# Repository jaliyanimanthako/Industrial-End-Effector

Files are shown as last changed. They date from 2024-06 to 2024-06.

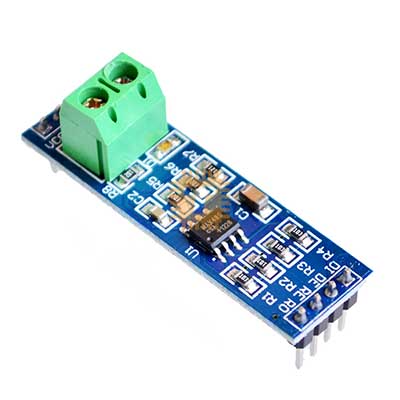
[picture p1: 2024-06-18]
Data Sets and Components/rs485.jpg

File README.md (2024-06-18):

# Industrial End Effector for Automated Pick and Place Robots

This repository contains the hardware and software documentation for an industrial end effector designed for automated pick and place robots. The project integrates ToF (Time-of-Flight) sensors with a vacuum gripper, facilitating precise orientation detection and efficient communication with robot control panels.

## Overview

The project focuses on:
- Integrating ToF sensors (VL53L0X) for accurate measurement of box yaw and pitch angles.
- Using Modbus protocol over USB for seamless data transmission.
- Designing a robust PCB layout and enclosure to optimize space and ensure reliable operation in industrial environments.

## Features

- **Modbus Protocol Integration**: Enables reliable serial communication between the end effector and robot control panels.
- **ToF Sensors (VL53L0X)**: Facilitates precise box orientation detection essential for pick and place operations. 
  - *Library Usage*: Includes a detailed comparison between library usage and direct register-level programming for optimizing memory usage.
- **MAX485 TTL to RS485 Converter Module**: Converts TTL signals for long-distance communication.  
- **USB to RS485 Communication Module**: Used for debugging and monitoring via PC.

  rs485

- **PCB Design**: Optimized layout for component integration and space efficiency.

WhatsApp Image 2024-06-18 at 14 25 22_f2b9fc5d

- **Enclosure Design**: Ensures secure attachment and robust mechanical strength for various vacuum gripper sizes.
  - *Adjustable Design Challenges*: Discusses challenges and solutions related to accommodating different vacuum gripper sizes.
  - *Final Design*: Details the chosen enclosure design tailored for specific vacuum gripper models.

## Components

- **Microcontroller**: ATMEGA2560-16AU for data handling and communication.
- **Multiplexer**: PCA9546ADG4 manages I2C signals from multiple ToF sensors.
- **Crystal Oscillator**: ABLS2-16.000MHZ-D4Y-T provides stable clock signal.
- **Capacitors, Resistors, LEDs**: Essential components for power management, circuit configuration, and status indication.
- **Headers and Connectors**: Facilitate external connections and USB connectivity.

## Usage

1. **Setup**:
   - Connect the ToF sensors and components as per the hardware documentation.
   - Ensure proper power supply and USB connectivity for data transmission.

2. **Programming**:
   - Use the provided software libraries or customize firmware based on project requirements.
   - Implement Modbus communication protocols for seamless integration with robot control systems.

3. **Testing and Debugging**:
   - Utilize Modbus Poll software for monitoring data transmission and debugging.
   - Verify sensor accuracy and functionality before deployment.

## Enclosure Design

The enclosure design ensures:
- Secure attachment and mechanical strength suitable for various vacuum gripper models.
- Dedicated mounting places for ToF sensors (VL53L0X) to avoid interference with gripper functionality.
- Features like air vents for heat dissipation and mounting bosses for PCB, ensuring robustness and ease of access.

</p center>
 
 </p>



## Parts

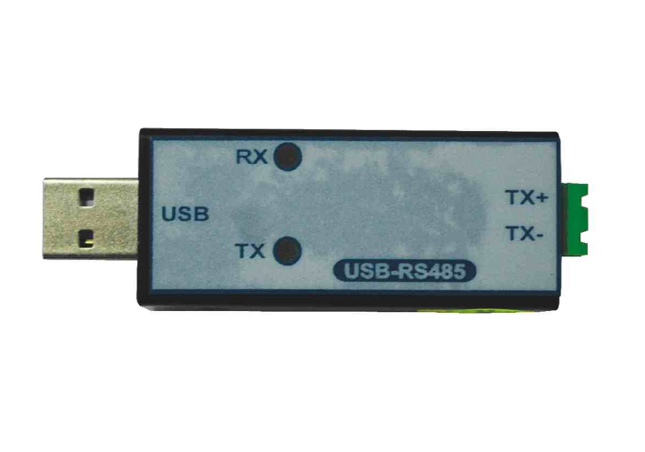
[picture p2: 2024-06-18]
Data Sets and Components/usb.png

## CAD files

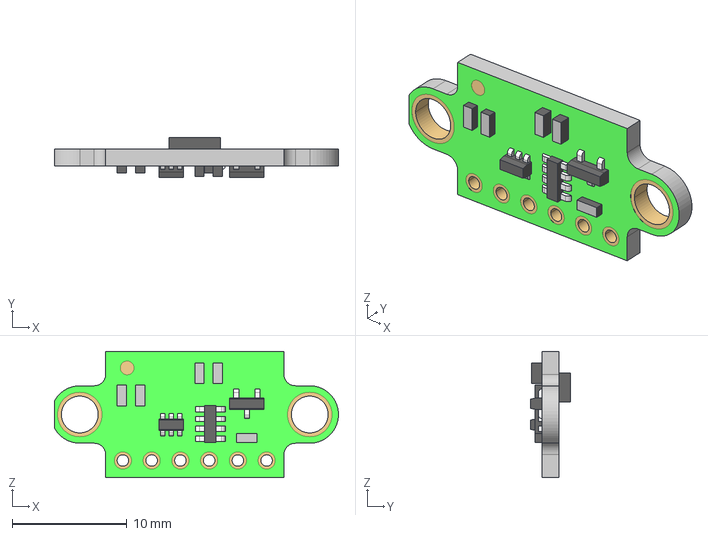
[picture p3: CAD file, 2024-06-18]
Data Sets and Components/vl53l0x for conceptual.stp
24.7 x 3.50 x 11.0 mm

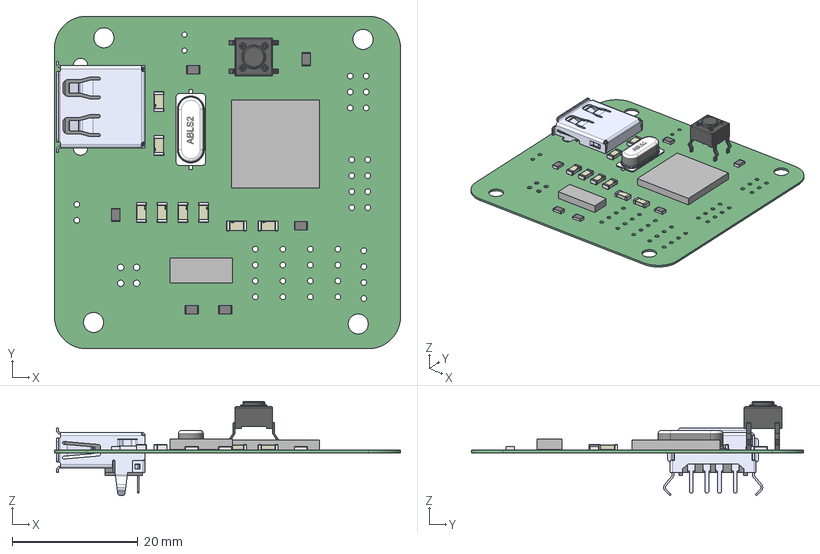
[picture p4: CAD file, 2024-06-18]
Enclosure Designs/PCB2 For Conceptual.step
55.1 x 53.0 x 15.0 mm
Mid_Body x 6
Mark x 6
Cap_KEMET_C1206C472K4RACTU_eec x 24
Extruded x 2
Switch_C&K_PTS645SM43SMTR92LFS_eec

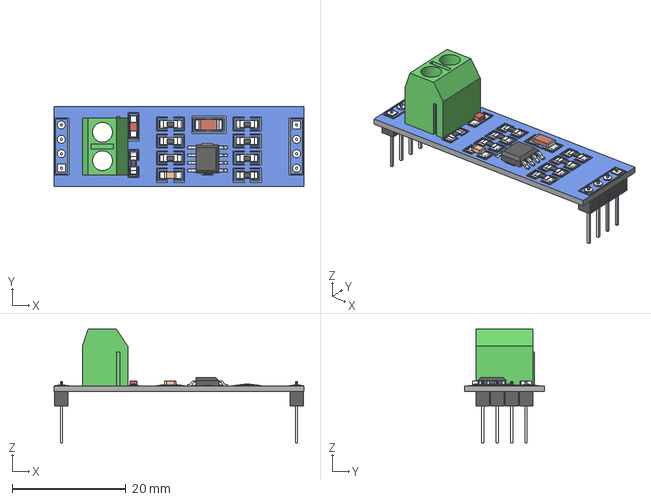
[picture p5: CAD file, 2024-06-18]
Data Sets and Components/rs485 for conseptual.stp
44.0 x 14.0 x 20.0 mm

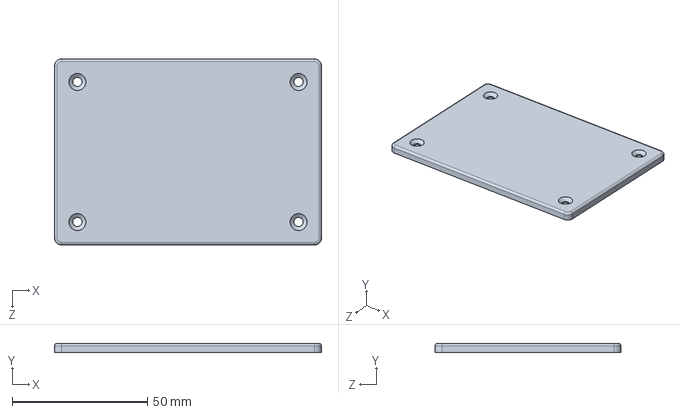
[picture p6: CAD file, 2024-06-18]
Enclosure Designs/Lid for the final design.SLDPRT
98.8 x 3.50 x 68.8 mm

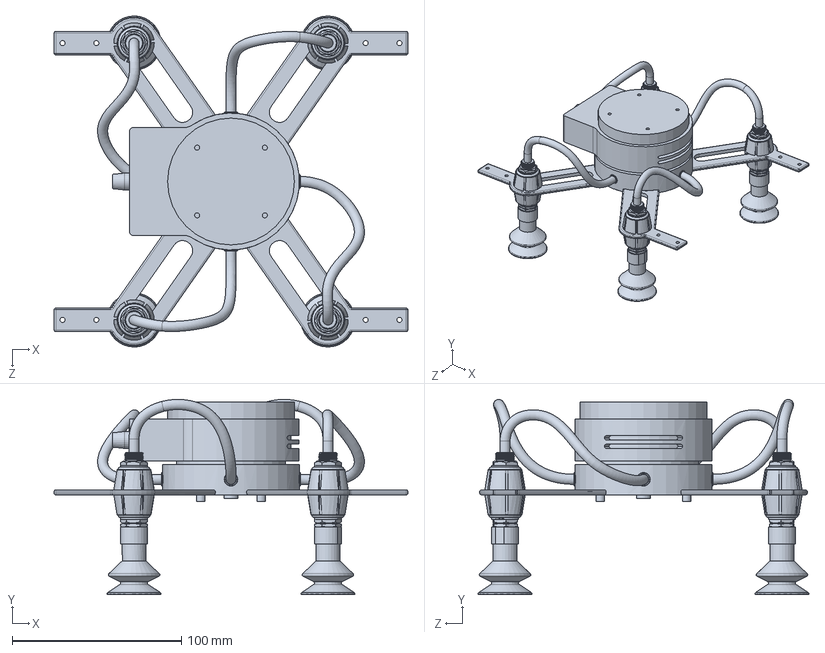
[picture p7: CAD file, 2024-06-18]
Enclosure Designs/Vacuum gripper.SLDPRT
209.3 x 115.5 x 195.8 mm

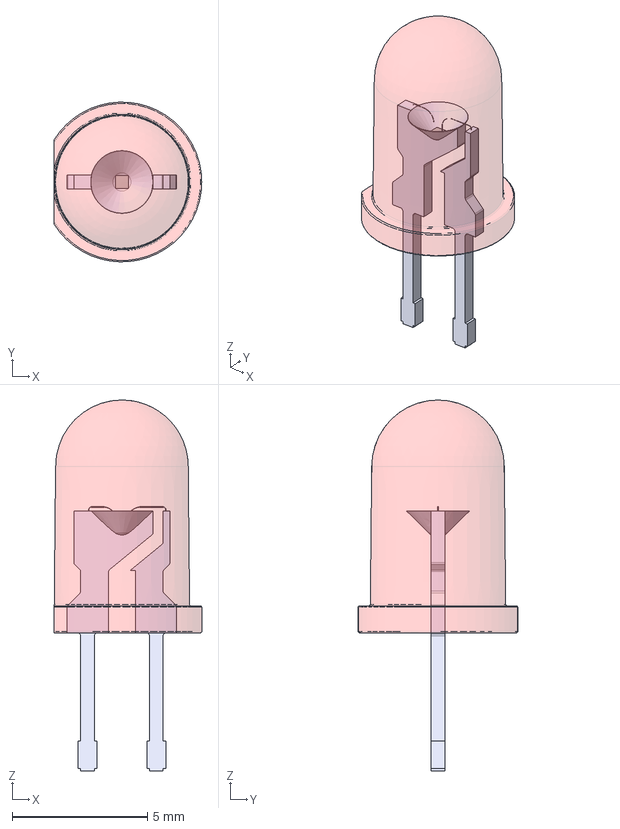
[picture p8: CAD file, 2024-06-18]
Enclosure Designs/LED D5 - Red-Clear_cutted conceptual.step
5.45 x 5.90 x 13.7 mm

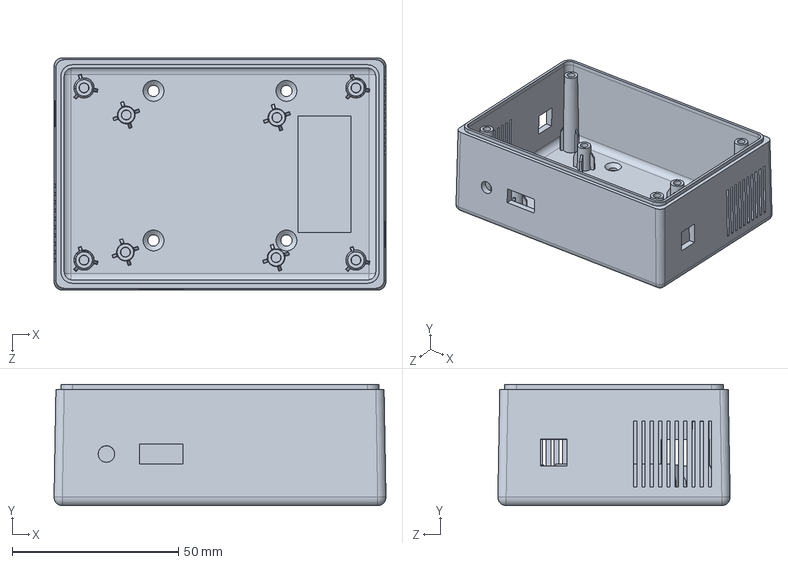
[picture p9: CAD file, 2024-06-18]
Enclosure Designs/Box of the gripper.SLDPRT
99.9 x 36.5 x 69.9 mm

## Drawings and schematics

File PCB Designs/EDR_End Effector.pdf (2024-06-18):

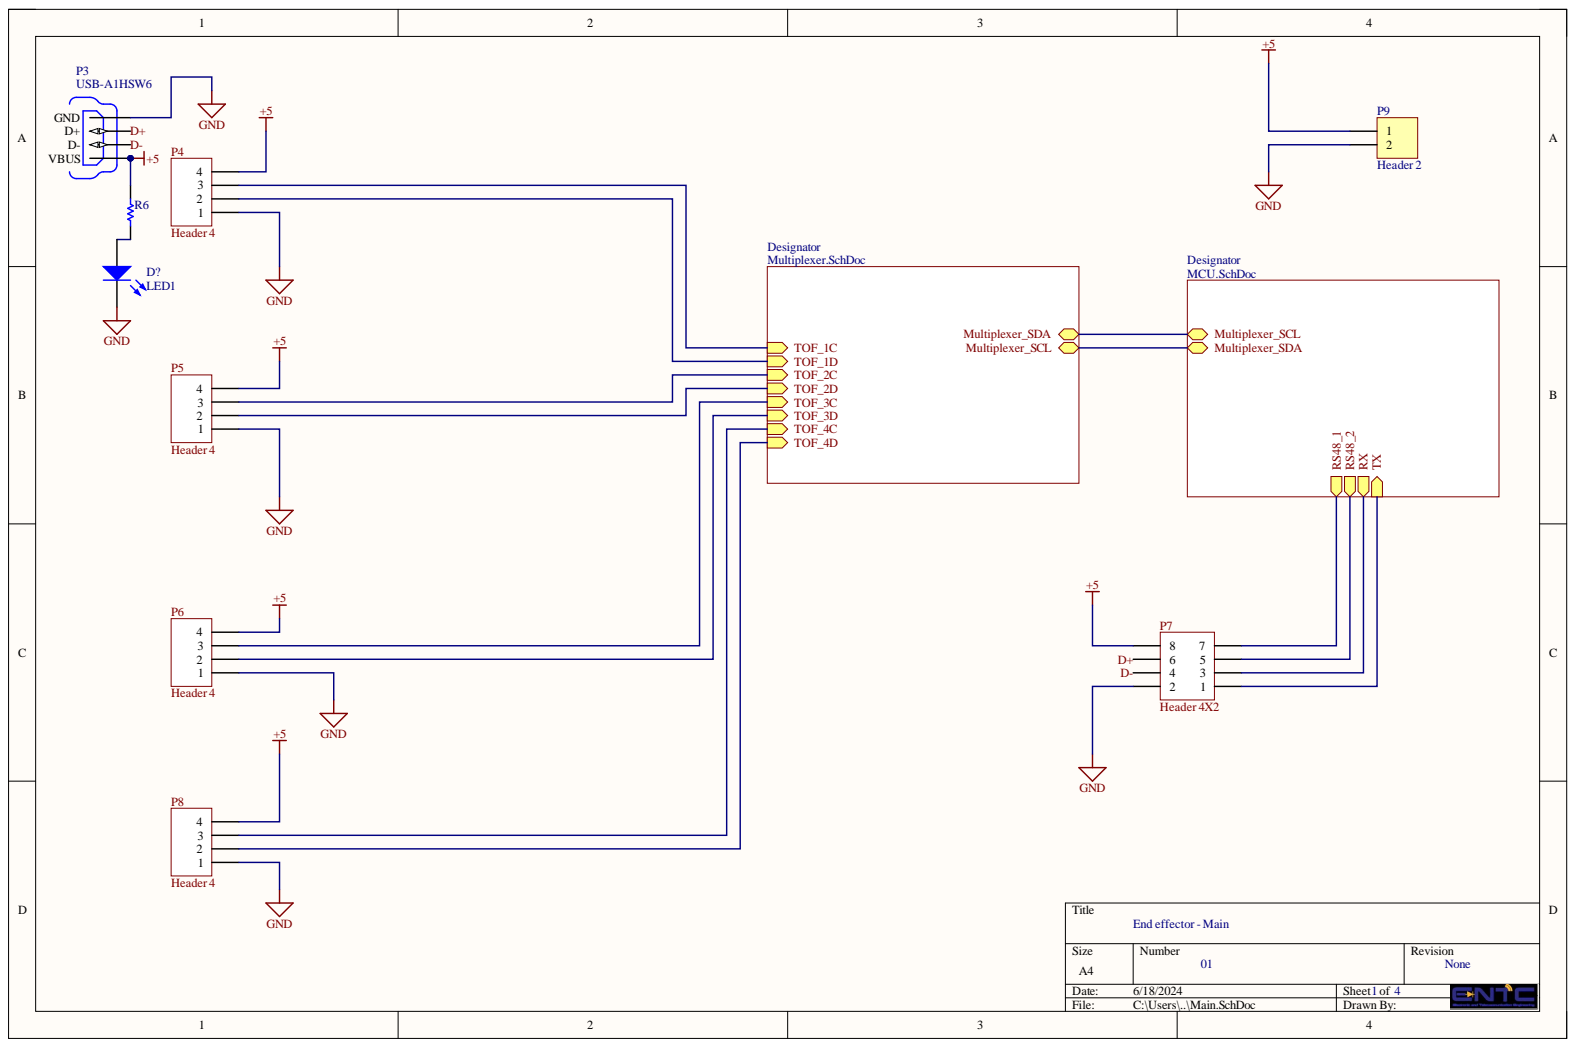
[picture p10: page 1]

GN + | Multiplexe r_ S D A TOF _ 1 C Multiplexe r _ S CL TOF _ 1 D TOF _2 C TOF _2 D TOF _ 3 C TOF _ 3 D TOF _4 C TOF _4 D

Siz e A4 | Numb e r 01 | R evisio n No n e

Da te : 6/18/202 4 | She et of 1 4
File : C:\Use rs\. .\Main . S c hD o c | Dr awn B y :

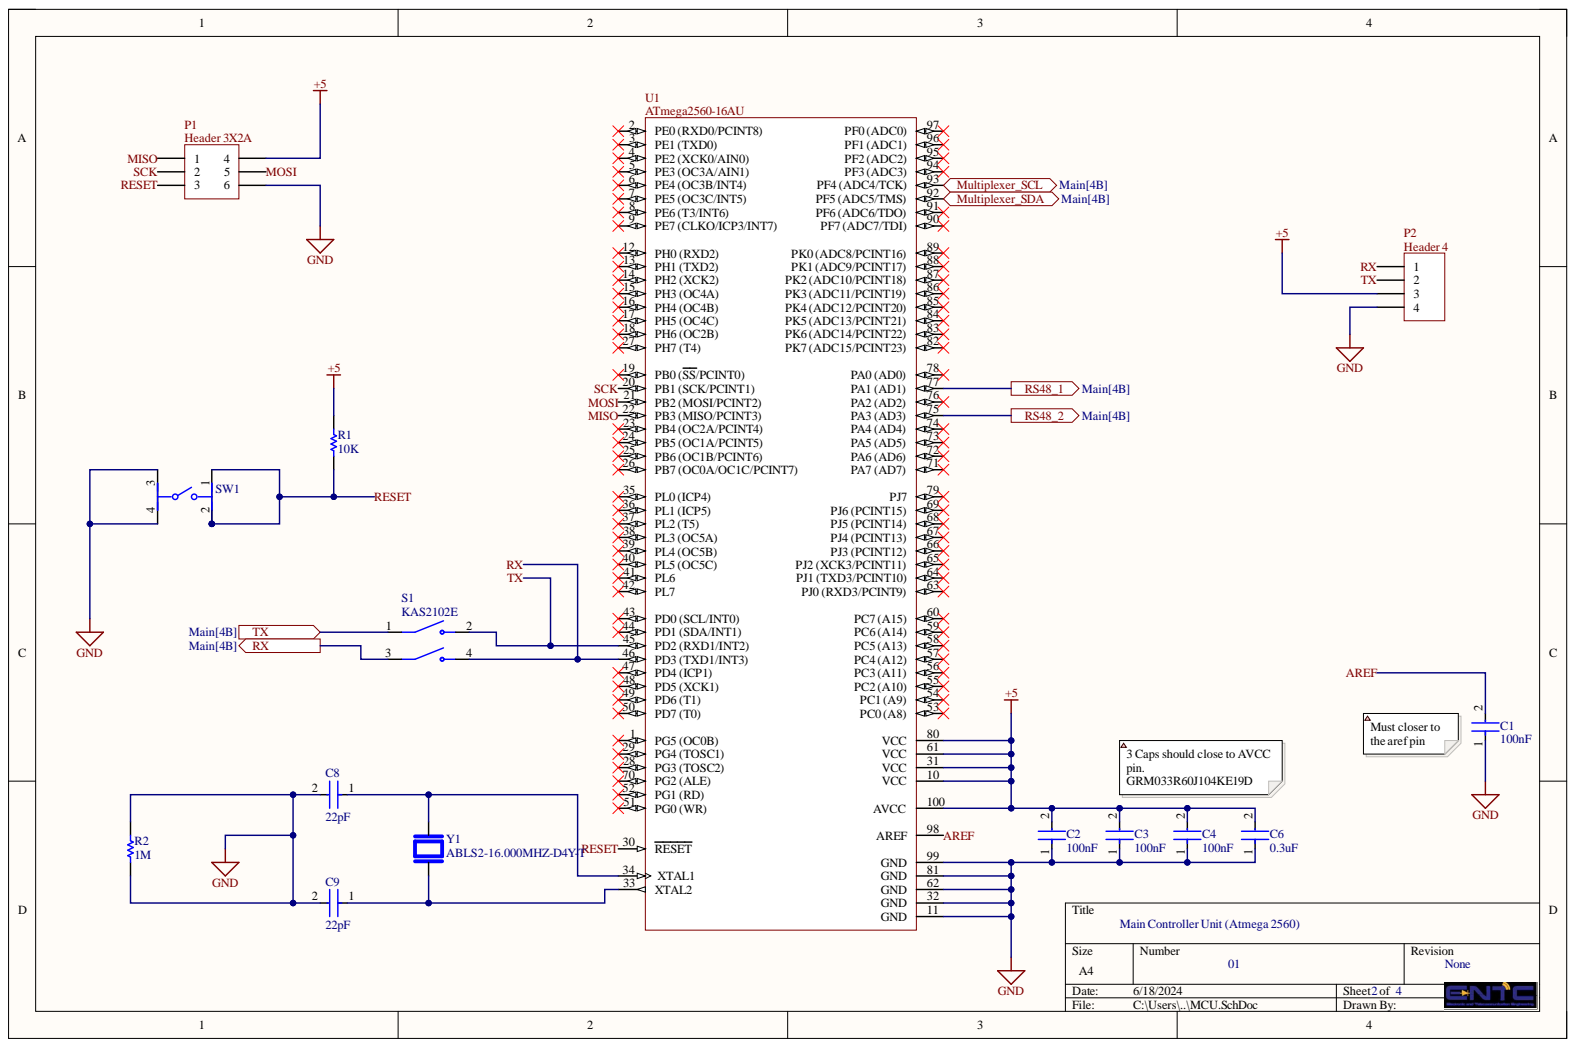
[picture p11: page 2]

Siz e A4 | Numb e r 01 | R evisio n No n e

Da te : 6/18/202 4 | She et of 2 4
File : C:\Use rs\. .\MCU. S c hD o c | Dr awn B y :

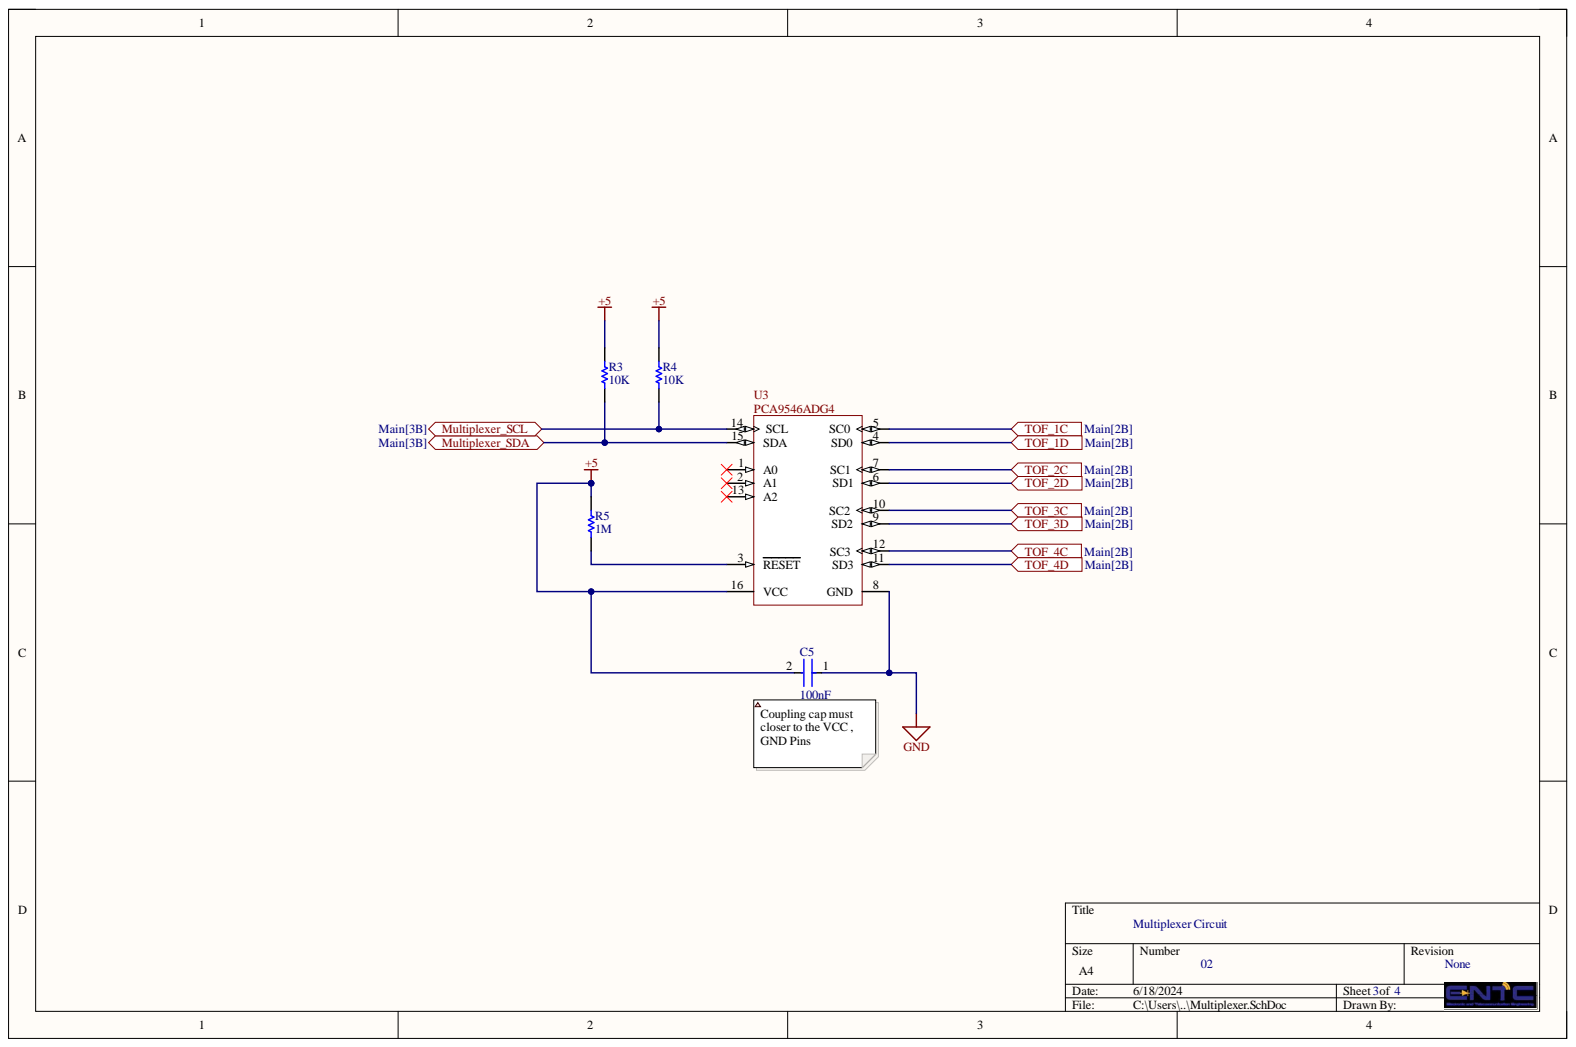
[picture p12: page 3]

Coupling cap must
closer to the VCC ,
GND Pins

Size A4 | Number 02 | Revision None

Date: 6/18/2024 | Sheet of 3 4
File: C:\Users\..\Multiplexer.SchDoc | Drawn By:

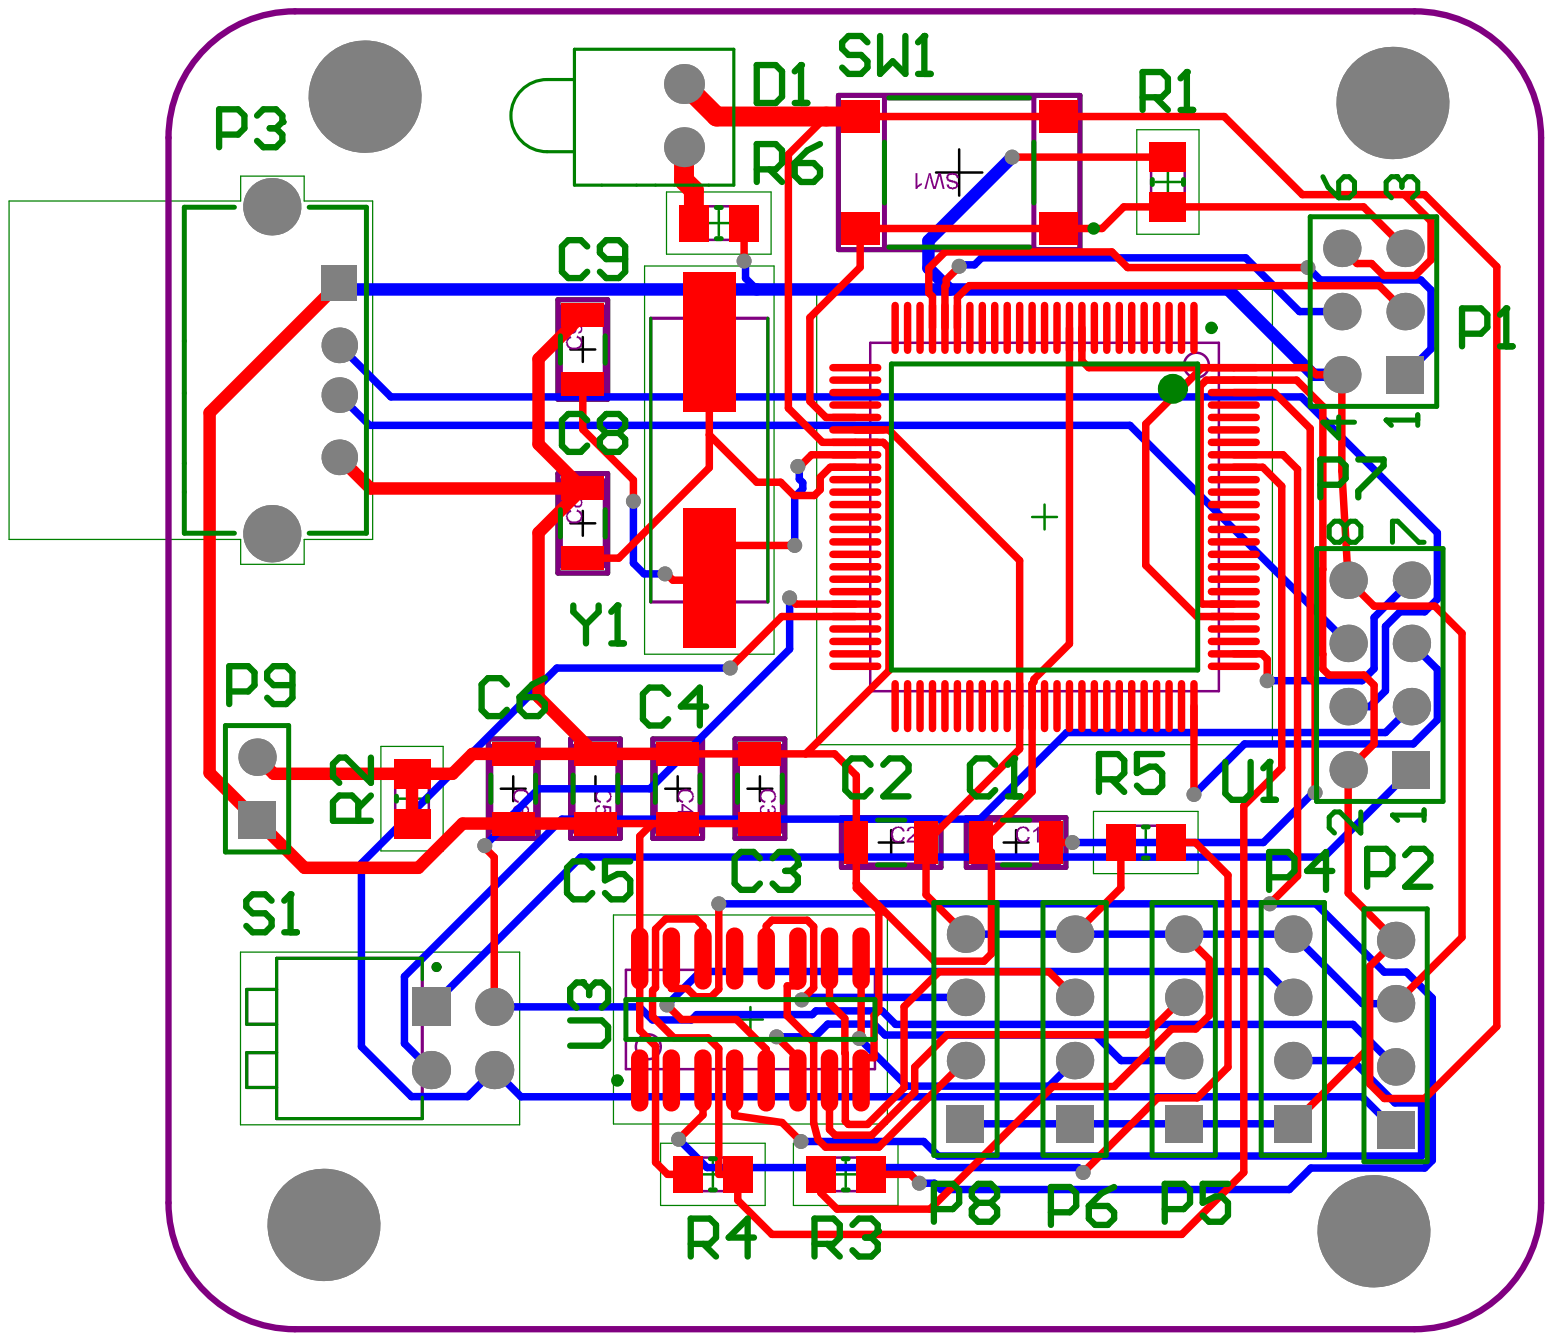
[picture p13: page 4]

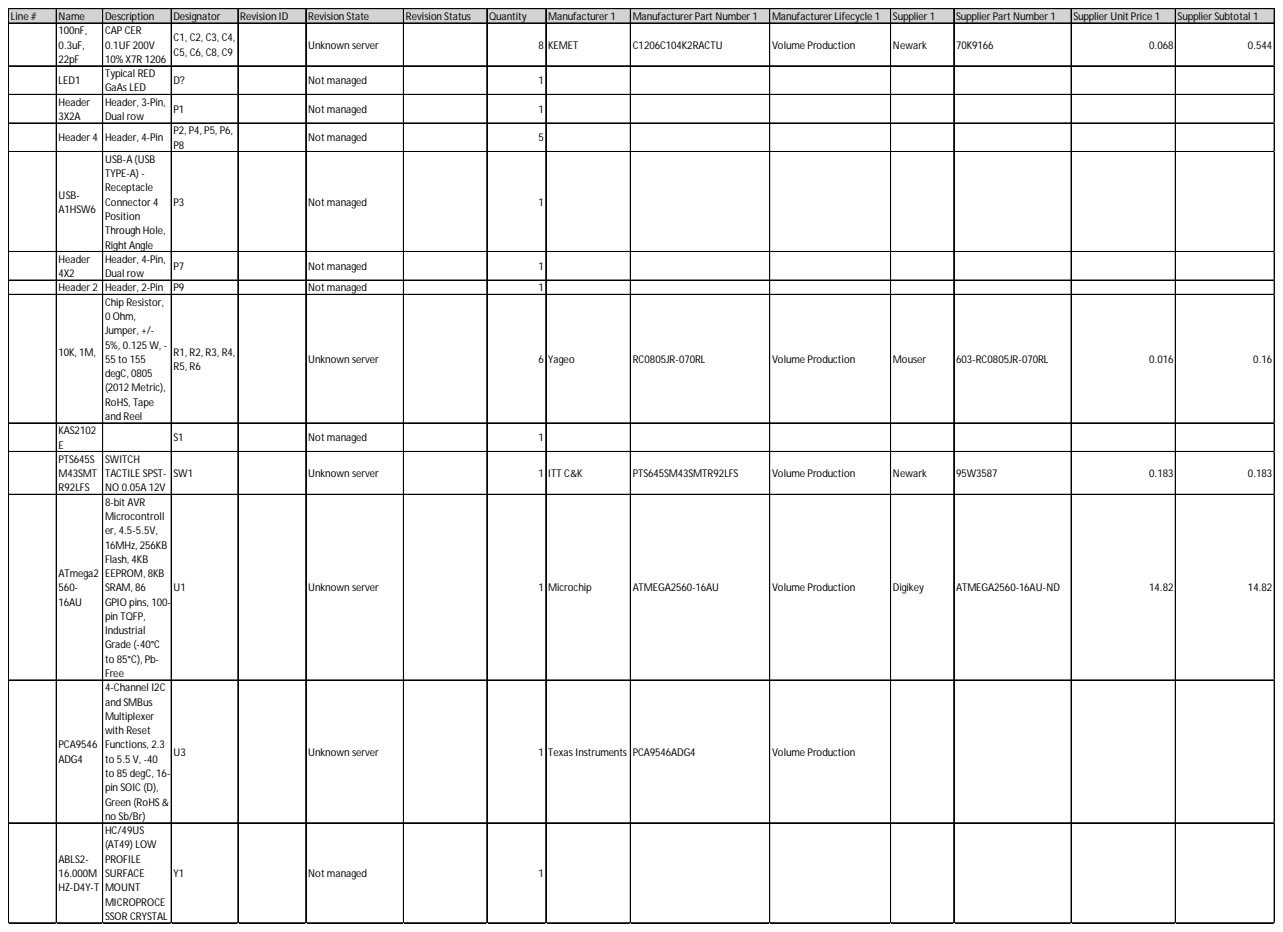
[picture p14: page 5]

Line # | Name | Description | Designator | Revision ID | Revision State | Revision Status | Quantity | Manufacturer 1 | Manufacturer Part Number 1 | Manufacturer Lifecycle 1 | Supplier 1 | Supplier Part Number 1 | Supplier Unit Price 1 | Supplier Subtotal 1

100nF, 0.3uF, 22pF | CAP CER 0.1UF 200V 10% X7R 1206 | C1, C2, C3, C4, C5, C6, C8, C9 | | Unknown server | | 8 KEMET | | C1206C104K2RACTU | Volume Production | Newark | 70K9166 | 0.068 | 0.544

LED1 | Typical RED GaAs LED | D? | | Not managed | | 1

Header 3X2A | Header, 3-Pin, Dual row | P1 | | Not managed | | 1

Header 4 | Header, 4-Pin | P2, P4, P5, P6, P8 | | Not managed | | 5

USB-A1HSW6 | USB-A (USB TYPE-A) -Receptacle Connector 4 Position Through Hole, Right Angle | P3 | | Not managed | | 1

Header 4X2 | Header, 4-Pin, Dual row | P7 | | Not managed | | 1

Header 2 | Header, 2-Pin | P9 | | Not managed | | 1
10K, 1M, | Chip Resistor, 0 Ohm, Jumper, +/-5%, 0.125 W, -55 to 155 degC, 0805 (2012 Metric), RoHS, Tape and Reel | R1, R2, R3, R4, R5, R6 | | Unknown server | | 6 Yageo | | RC0805JR-070RL | Volume Production | Mouser | 603-RC0805JR-070RL | 0.016 | 0.16

KAS2102 E | | S1 | | Not managed | | 1

PTS645S M43SMT R92LFS | SWITCH TACTILE SPST-NO 0.05A 12V | SW1 | | Unknown server | | 1 | ITT C&K | PTS645SM43SMTR92LFS | Volume Production | Newark | 95W3587 | 0.183 | 0.183

ATmega2 560-16AU | 8-bit AVR Microcontroll er, 4.5-5.5V, 16MHz, 256KB Flash, 4KB EEPROM, 8KB SRAM, 86 GPIO pins, 100-pin TQFP, Industrial Grade (-40°C to 85°C), Pb-Free | U1 | | Unknown server | | 1 | Microchip | ATMEGA2560-16AU | Volume Production | Digikey | ATMEGA2560-16AU-ND | 14.82 | 14.82

PCA9546 ADG4 | 4-Channel I2C and SMBus Multiplexer with Reset Functions, 2.3 to 5.5 V, -40 to 85 degC, 16-pin SOIC (D), Green (RoHS & no Sb/Br) | U3 | | Unknown server | | 1 | Texas Instruments | PCA9546ADG4 | Volume Production

ABLS2-16.000M HZ-D4Y-T | HC/49US (AT49) LOW PROFILE SURFACE MOUNT MICROPROCE SSOR CRYSTAL | Y1 | | Not managed | | 1

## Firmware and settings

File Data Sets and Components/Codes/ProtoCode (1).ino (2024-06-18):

#include "distance.h"

// // below values should be configured
float dv = 41; // vertical distance between the ToF sensors
float dhu = 76; // horizontal distance between the upper ToF sensors
float dhd = 76; // horizontal distance between the lower ToF sensors

// // below values are read and calculated
float relativeDistance;
float dlu; // left upper ToF sensor distance
float dru; // right upper ToF sensor distance
float dld; // left down ToF sensor distance
float drd; // right down ToF sensor distance
float thetaP; // pitch angle (angle around the horizontal axis)
float thetaY; // yaw angle (angle around the vertical axis)

void setup() {
  // put your setup code here, to run once:
  Serial.begin(9600);
  setID();
}

void loop() {
  // put your main code here, to run repeatedly:

  dlu = sensor_1() - 5;
  dru = sensor_2();
  dld = sensor_3();
  drd = sensor_4() - 4;

  relativeDistance = (dlu + dru + dld + drd)/4;

  thetaP = 0.5*atan((dlu-dld)/dv) + 0.5*atan((dru-drd)/dv);
  thetaY = 0.5*atan((dru-dlu)/dhu) + 0.5*atan((drd-dld)/dhd);

  thetaP = degrees(thetaP);
  thetaY = degrees(thetaY);

  Serial.print("Pelative Distance : " + String(relativeDistance) + " ");
  Serial.print("Pitch Angle : " + String(thetaP) + " ");
  Serial.println("Yaw Angle : " + String(thetaY) + " ");

  delay(20);
  
}
